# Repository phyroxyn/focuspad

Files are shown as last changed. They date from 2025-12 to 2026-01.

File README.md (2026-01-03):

# focuspad_v2

A compact 4×4 macropad for Windows productivity workflows (Fusion 360, Bambu Studio, Adobe Illustrator/Photoshop, DaVinci Resolve). It features two knobs: the **left knob is a push-button only** (purely for aesthetics), while the **right knob is a real rotary encoder** for volume control.

## Render
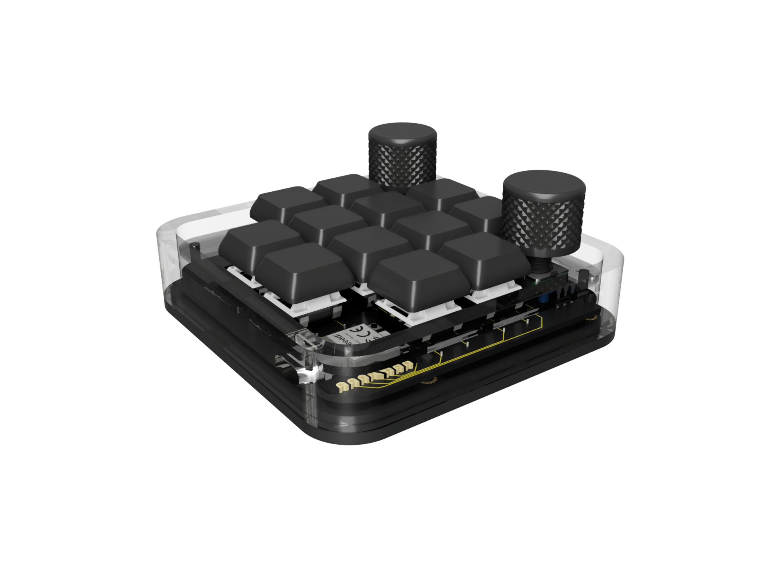
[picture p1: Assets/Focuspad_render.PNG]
focuspad_v2 render

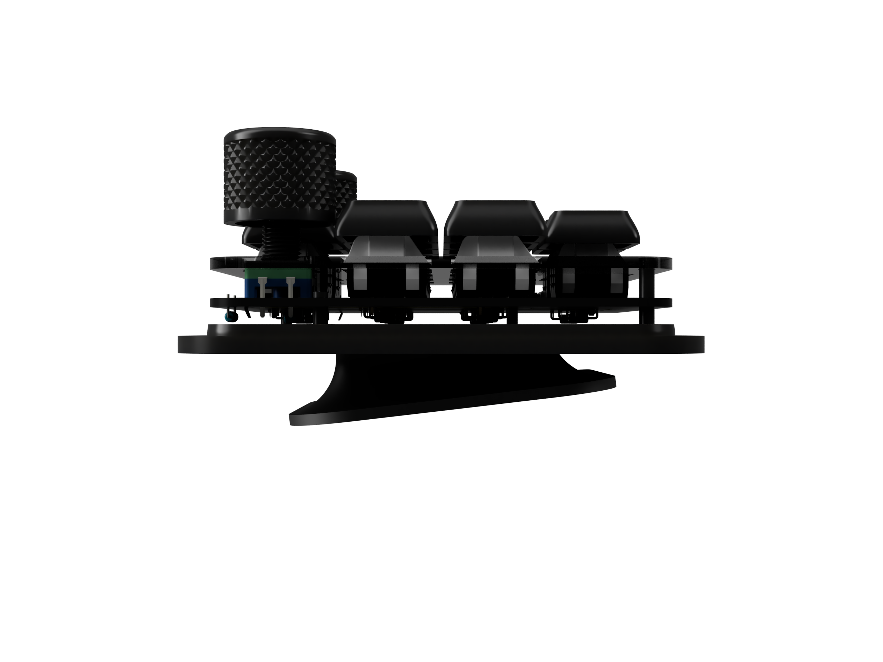
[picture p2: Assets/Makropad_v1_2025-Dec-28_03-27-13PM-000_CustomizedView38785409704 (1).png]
focuspad_v2 side view

## PCB
### Schematic
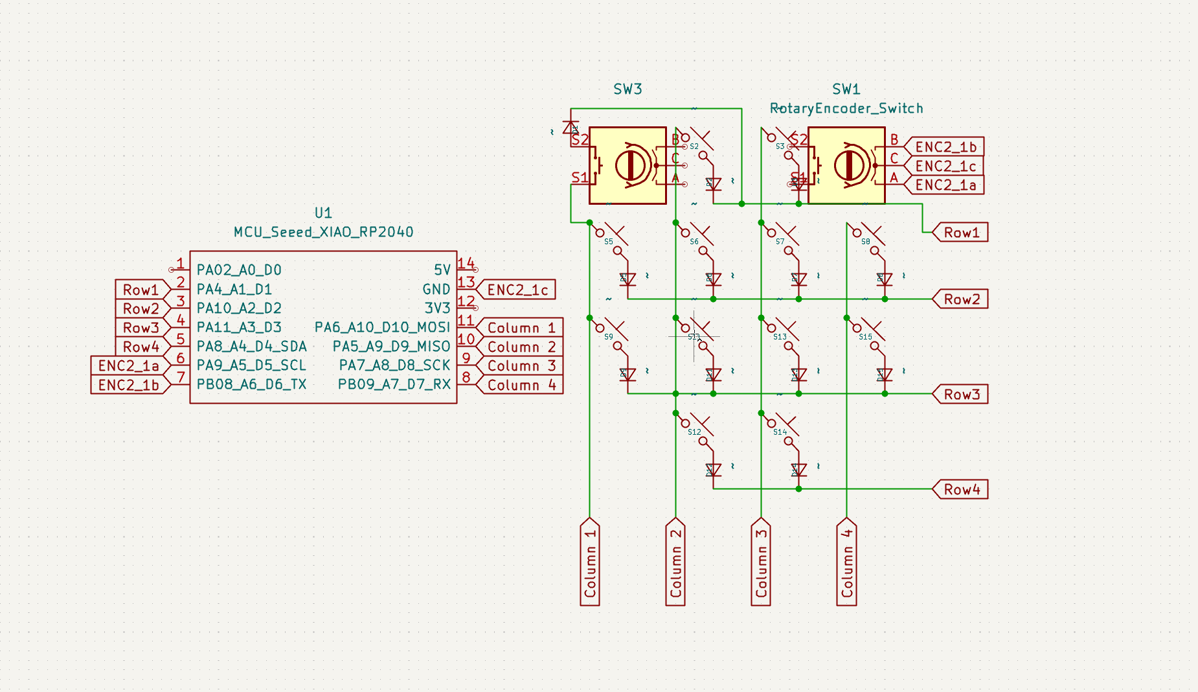
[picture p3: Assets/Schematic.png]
Schematic


### PCB Layout
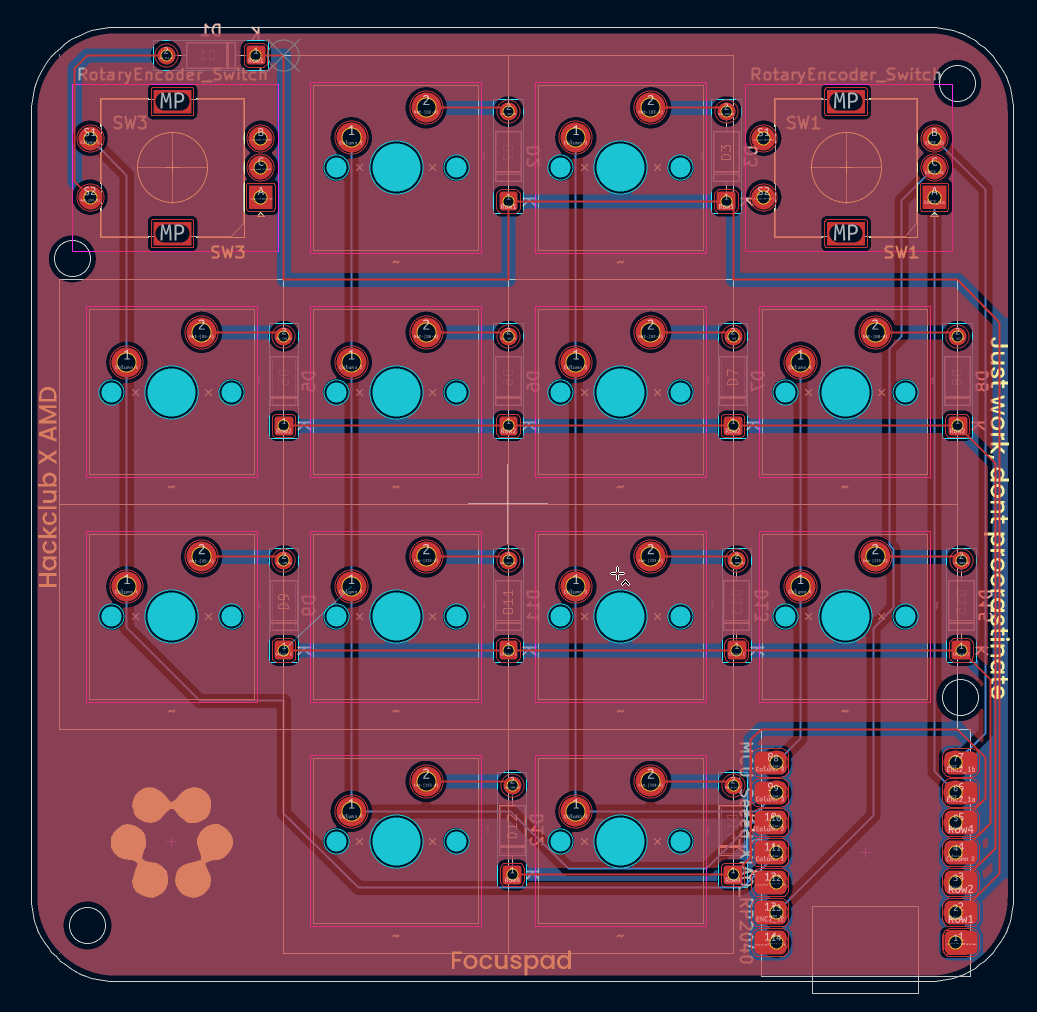
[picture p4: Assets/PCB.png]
PCB


## Case
The enclosure is designed as **five parts**:
- **Top cover** (protects the PCB; acrylic would look great).
- **Base** (with heat-set insert holes to mount the PCB and top cover).
- **Side cover** (hides the PCB ; would look great in milled aluminum).
- **Sub-base / stand** (tilts the macropad at an ergonomic angle).
- **Connector** (connects the base with the stand).

## Firmware
Firmware is written in QMK.
- Left knob: **push-button only** → Mute/Unmute.
- Right knob: **rotary encoder** → Volume Up/Down.
- The 12 keys are mapped to common Windows shortcuts.

QMK setup help:
- https://docs.qmk.fm/#/getting_started_build_tools 
- https://docs.qmk.fm/#/getting_started_make_guide 
- https://youtu.be/BcXycScePHM?t=360&si=u64MpJI-V58_fIYx

## Bill of Materials (BOM)
| Item | Qty | Notes / Part |
|---|-----|---|
| [Seeed Studio XIAO RP2040](https://wiki.seeedstudio.com/XIAO-RP2040/) (through-hole) | 1 | Main MCU |
|MX brown switches| 12 | 4×4 grid, corners missing |
| Keycaps | 12 | [**low profile**, black](https://shop.beekeeb.com/products/smolo-low-profile-keycap) |
| Rotary encoder (EC11, 15mm)(w. **push putton**) | 2 | Right&left knob (rotary) |
| Diodes (1N4148, through-hole) | 13 | For matrix and left encoder|
| Rotary encoder caps|2|Cool locking and **black**|
|(3D printed parts) | 5|Black Petg/ aluminium & plexiglas|
| M3 heat-set inserts (M3×5×4) | 4 | Case mounting |
| M3 screws | 4 | Case mounting |
|PCB|1|Black PCB(Solder mask)|

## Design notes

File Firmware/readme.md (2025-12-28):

# focuspad_v2

focuspad_v2

A compact 4x4 macropad for productivity shortcuts, with a rotary encoder.

- Keyboard Maintainer: [phineas](https://github.com/phyroxyn)
- Hardware Supported: Custom Focuspad_v2 PCB, Seeed Studio XIAO RP2040 (Pro Micro compatible footprint)
- Hardware Availability: Private build / custom PCB (add a link if you publish it)

## Building and flashing

Build firmware (after setting up your build environment):

    make focuspad_v2:default

Flash firmware:

    make focuspad_v2:default:flash

See the [build environment setup](https://docs.qmk.fm/#/getting_started_build_tools) and the
[make instructions](https://docs.qmk.fm/#/getting_started_make_guide) for more information.  
Brand new to QMK? Start with the [Complete Newbs Guide](https://docs.qmk.fm/#/newbs). [web:1679][web:1456]

## Bootloader

Enter the bootloader in 3 ways: [web:1678]

- **Bootmagic reset**: Hold down the key at (0,0) in the matrix (usually the top-left key) and plug in the keyboard. [web:1678]
- **Physical reset button**: Briefly press the reset button on the controller/PCB (or short the reset pads, if present). [web:1678]
- **Keycode in layout**: Press the key mapped to `QK_BOOT` if it is available. [web:1678]

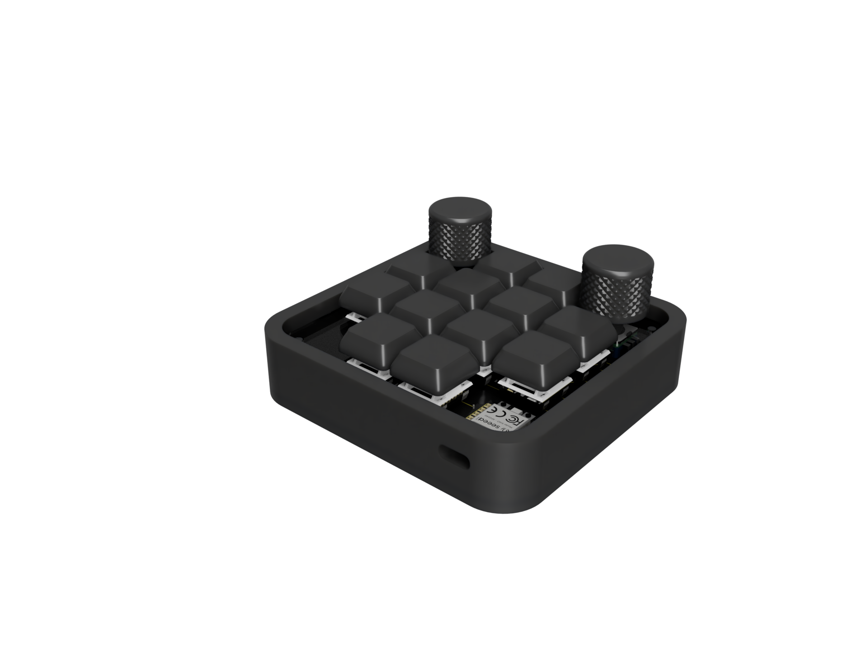
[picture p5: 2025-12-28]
Assets/Render_3Dprinted.png

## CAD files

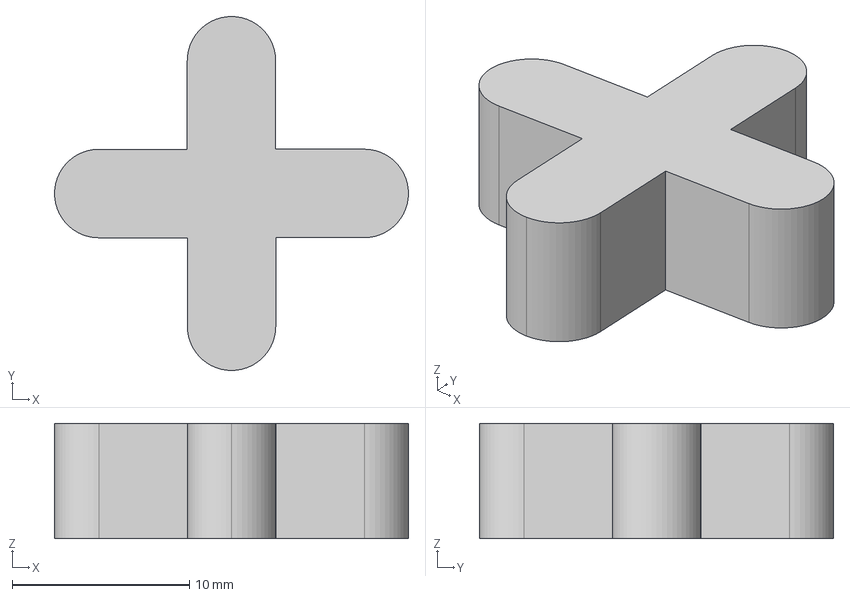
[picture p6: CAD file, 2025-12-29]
Production/Connector.step
20.0 x 20.0 x 6.50 mm

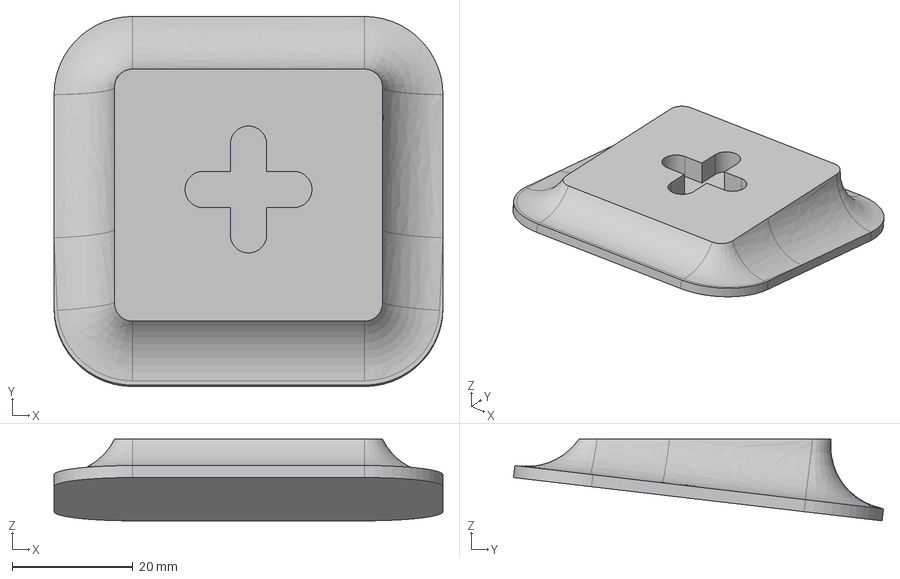
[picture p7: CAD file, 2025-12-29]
Production/Subbase.step
64.3 x 61.2 x 13.5 mm

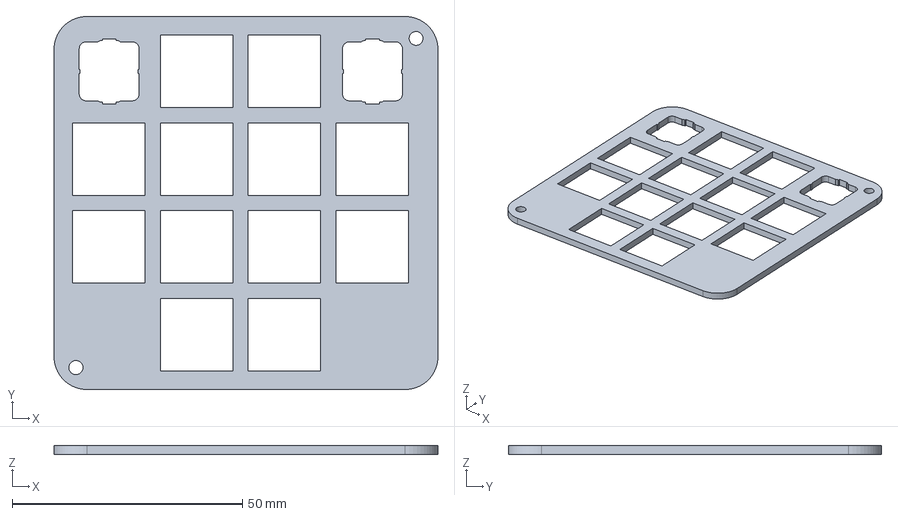
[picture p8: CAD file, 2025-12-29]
Production/Top.step
83.3 x 81.0 x 2.00 mm

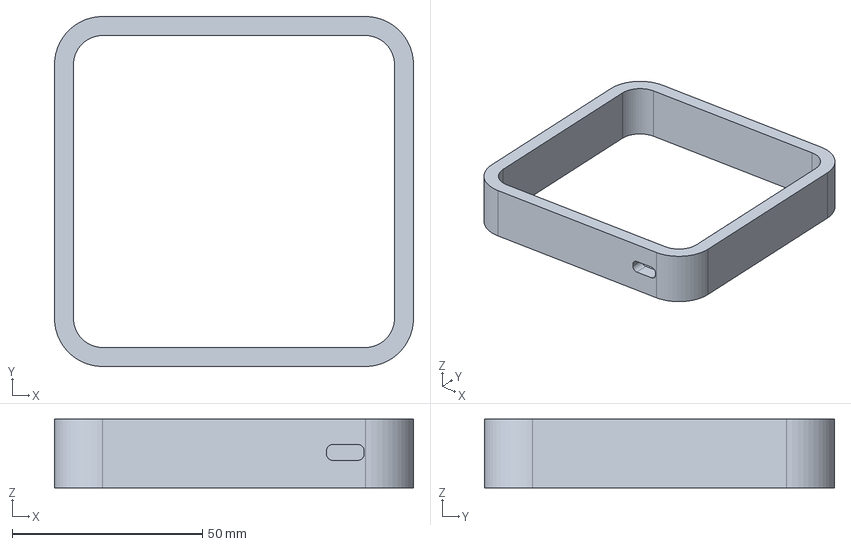
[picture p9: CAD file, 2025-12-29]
Production/Case.step
94.3 x 92.0 x 18.0 mm

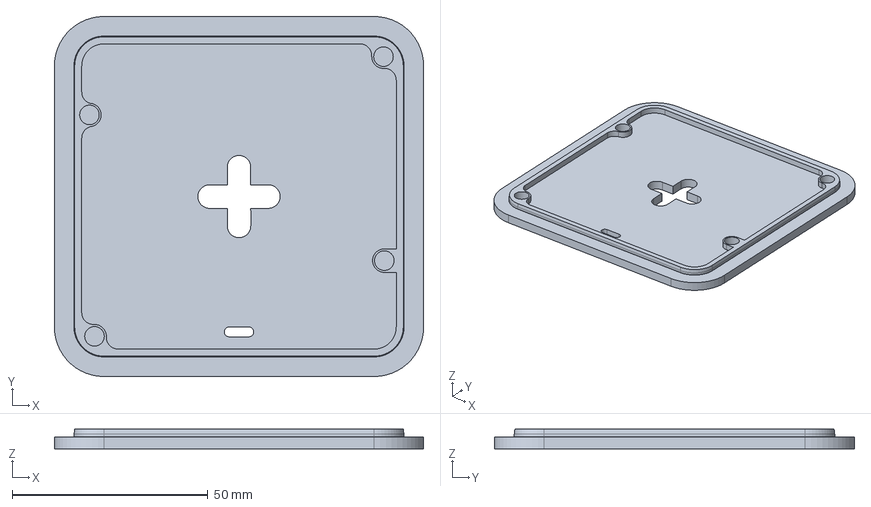
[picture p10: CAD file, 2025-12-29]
Production/Base.step
94.3 x 92.0 x 5.00 mm

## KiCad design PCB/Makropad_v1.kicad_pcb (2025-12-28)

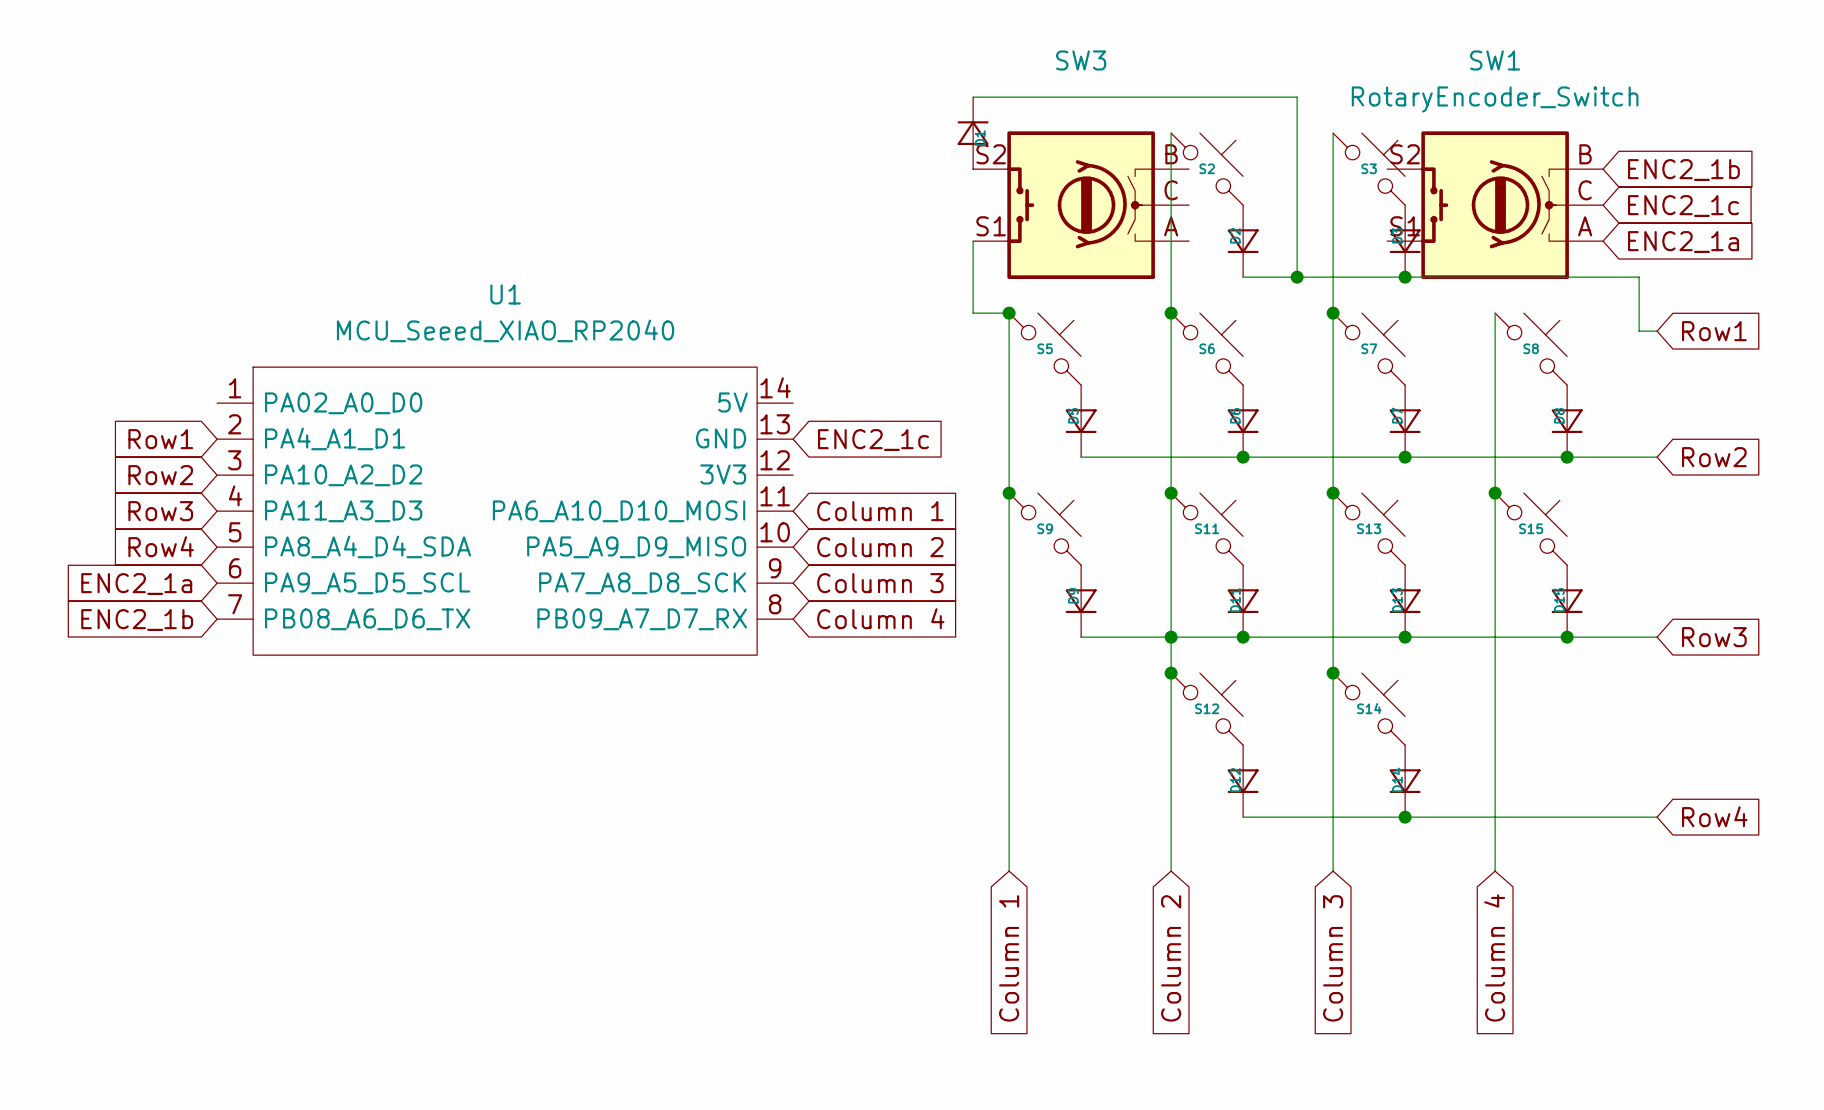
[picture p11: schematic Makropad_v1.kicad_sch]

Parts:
D1, D2, D3, D5, D6, D7, D8, D9, D11, D12, D13, D14, D15: D_DO-35_SOD27_P7.62mm_Horizontal
S2, S3, S5, S6, S7, S8, S9, S11, S12, S13, S14, S15: MX_Solder_1.00u
SW1, SW3: RotaryEncoder_Switch; RotaryEncoder_Alps_EC11E-Switch_Vertical_H20mm
U1: MCU_Seeed_XIAO_RP2040; Seeed_XIAO_RP2040

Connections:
Column 1: S5.1, S9.1, SW3.S1, U1.11 (PA6_A10_D10_MOSI)
Column 2: D9.1 (K), D11.1 (K), D13.1 (K), D15.1 (K), S2.1, S6.1, S11.1, S12.1, U1.4 (PA11_A3_D3), U1.10 (PA5_A9_D9_MISO)
Column 3: S3.1, S7.1, S13.1, S14.1, U1.9 (PA7_A8_D8_SCK)
Column 4: S8.1, S15.1, U1.8 (PB09_A7_D7_RX)
ENC2_1a: SW1.A, U1.6 (PA9_A5_D5_SCL)
ENC2_1b: SW1.B, U1.7 (PB08_A6_D6_TX)
ENC2_1c: SW1.C, U1.13 (GND)
unnamed: D1.2 (A), SW3.S2
unnamed: D2.2 (A), S2.2
unnamed: D3.2 (A), S3.2
unnamed: D5.2 (A), S5.2
unnamed: D6.2 (A), S6.2
unnamed: D7.2 (A), S7.2
unnamed: D8.2 (A), S8.2
unnamed: D9.2 (A), S9.2
unnamed: D11.2 (A), S11.2
unnamed: D12.2 (A), S12.2
unnamed: D13.2 (A), S13.2
unnamed: D14.2 (A), S14.2
unnamed: D15.2 (A), S15.2
Row1: D1.1 (K), D2.1 (K), D3.1 (K), U1.2 (PA4_A1_D1)
Row2: D5.1 (K), D6.1 (K), D7.1 (K), D8.1 (K), U1.3 (PA10_A2_D2)
Row4: D12.1 (K), D14.1 (K), U1.5 (PA8_A4_D4_SDA)

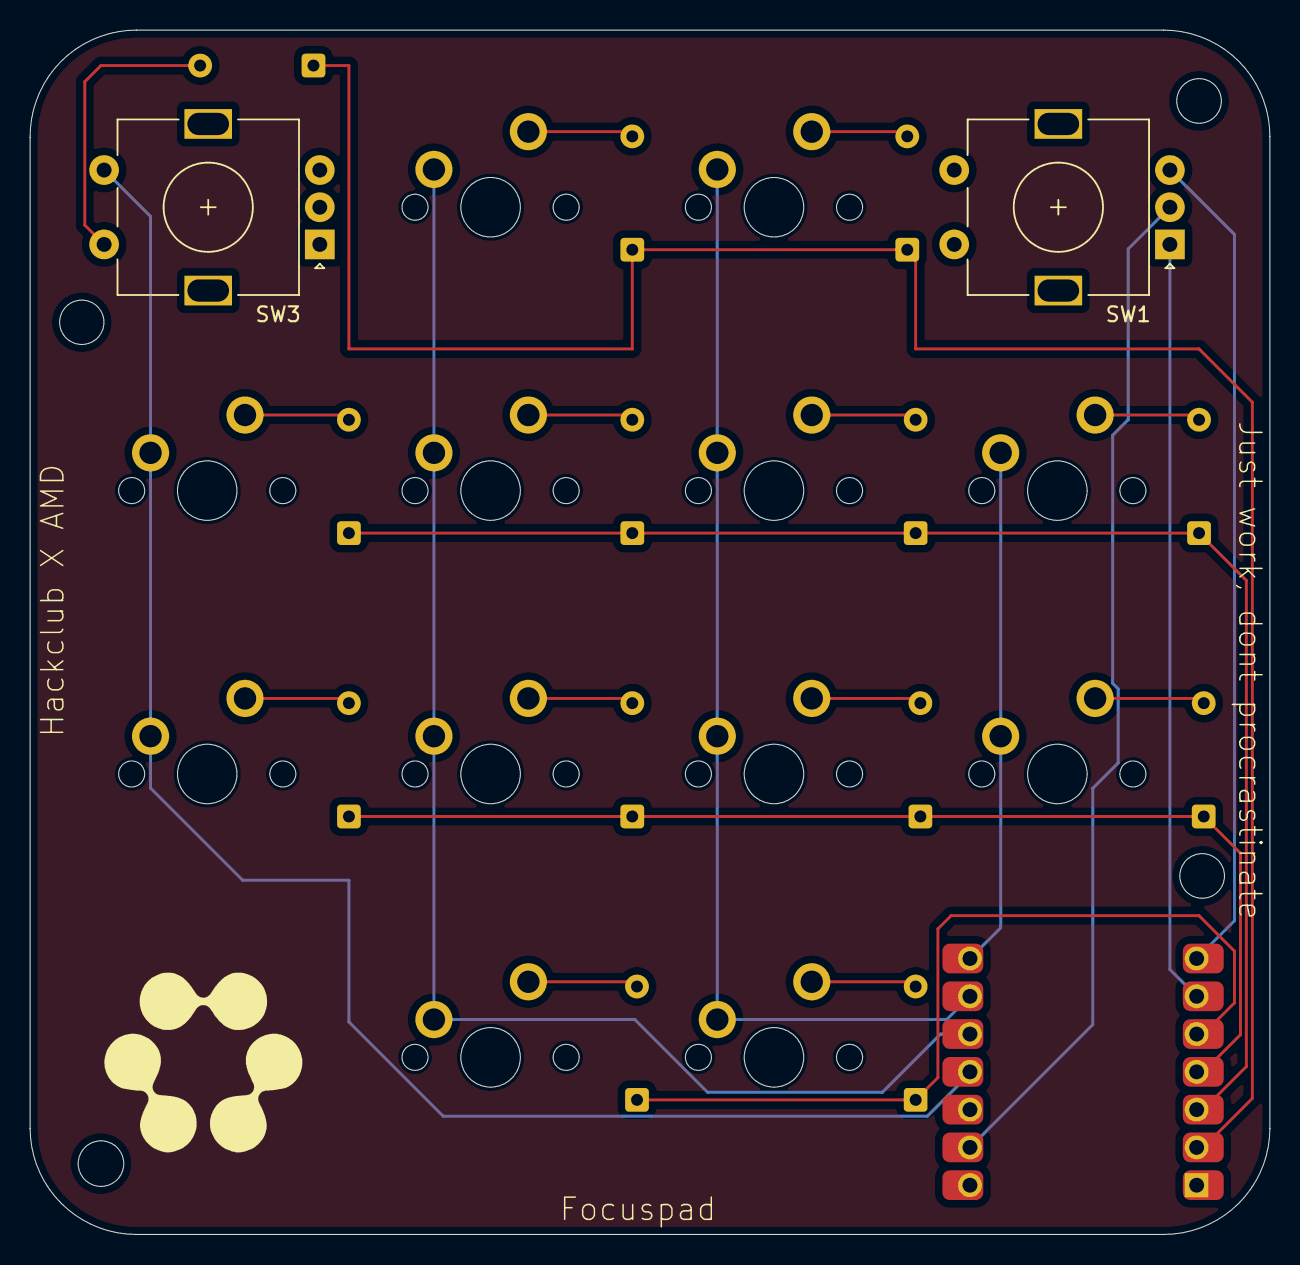
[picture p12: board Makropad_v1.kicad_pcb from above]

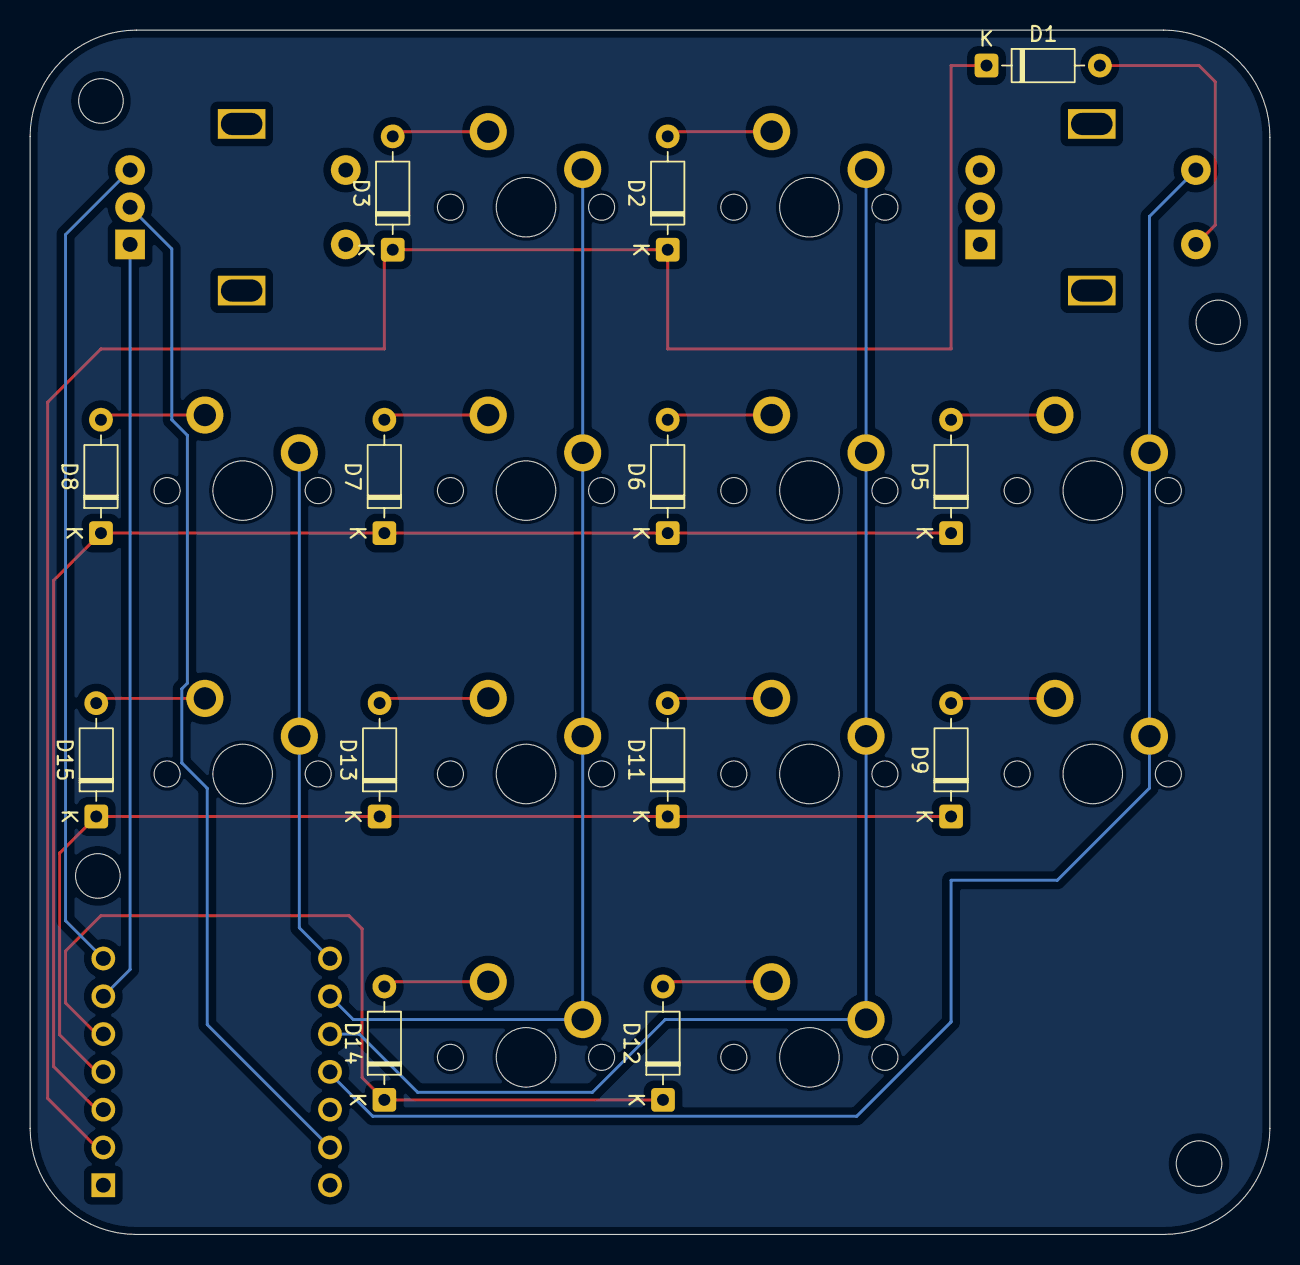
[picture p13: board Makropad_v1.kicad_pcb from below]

Board: 2 copper layers, 83.3 x 81.0 mm, 28 parts (13 on the bottom side), 23 nets.
